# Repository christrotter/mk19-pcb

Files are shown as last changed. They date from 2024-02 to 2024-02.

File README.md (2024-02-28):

# mk19-pcb
The antithesis of 'keep it simple, stupid' - all the features, all the time.

Do you need...
- To use the [Cyboard flex-pcb system](https://www.cyboard.digital/product-page/dactyl-flex-pcbs)?  [and extend it?](https://github.com/christrotter/macropad-pcb)?
- Two [Ultrafalcons](https://github.com/christrotter/ultrafalcon)...per side?
- SPI devices
  - PMW3360/3389 (_right side only_)
  - Dual GC9A01 TFTs per side
  - Quad-shift register-powered 32 pins for rows/cols? ([available as a dedicated breakout here](https://github.com/christrotter/shift-register-spi-breakout-pcb))
- [5-way switch](https://github.com/christrotter/5way-pcb) or [RKJXT](https://github.com/christrotter/rkjxt-mini-breakout) for arrow keys?
- Perhaps enough RGB to illumine your entire home? (_and almost certainly require 5v supplementary power - a feature, not a bug!_)  
- Audio and ADC breakouts?  Reset switch? Power and debug breakouts?
- And use an existing RP Pico to do it?

...probably not, which is why I had to design my own pcb.  So here it is...

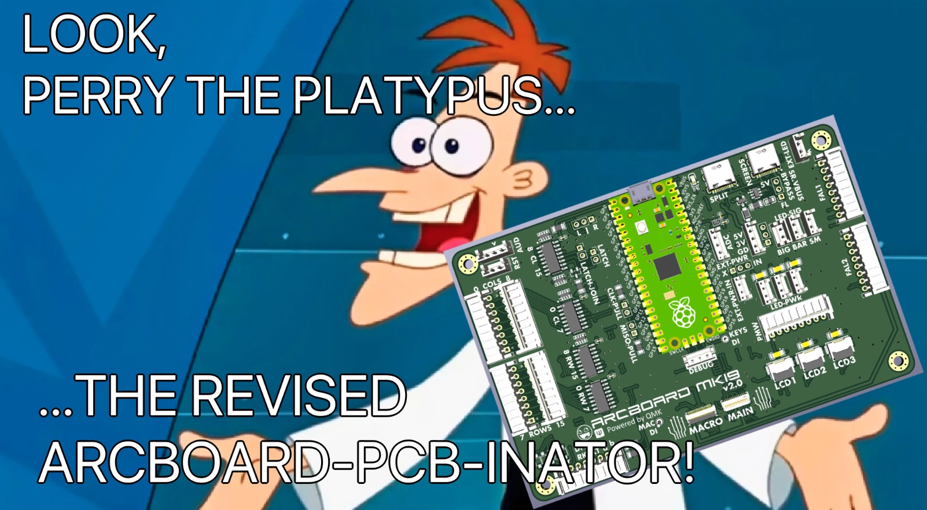
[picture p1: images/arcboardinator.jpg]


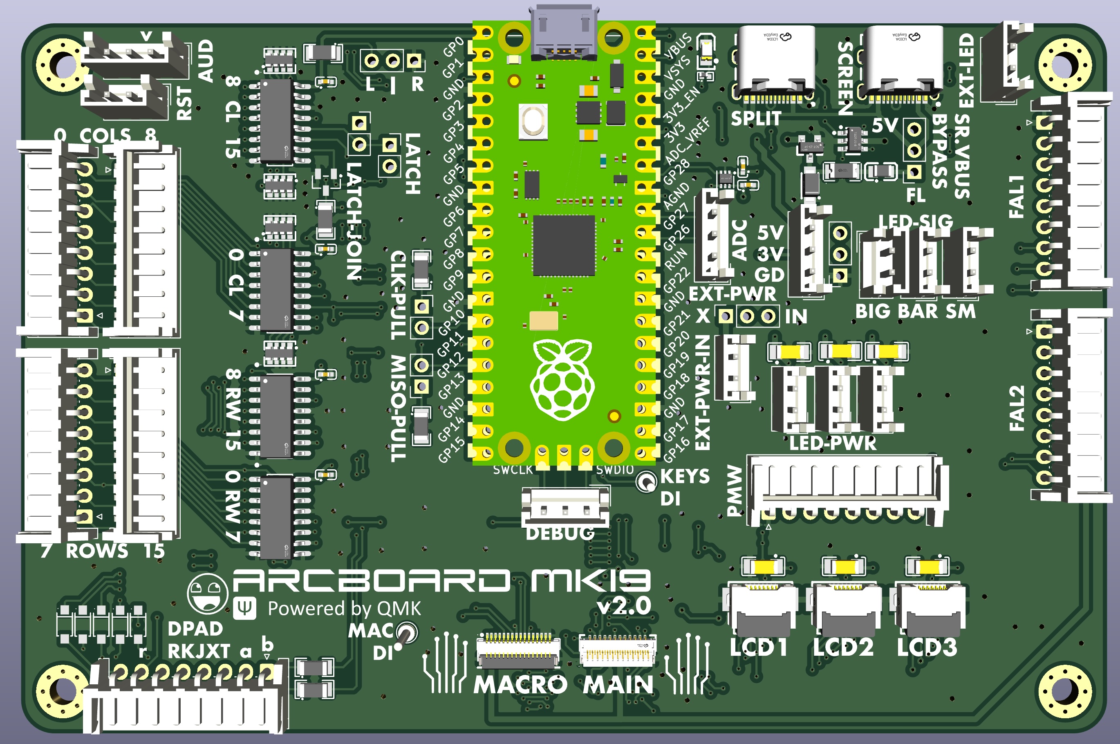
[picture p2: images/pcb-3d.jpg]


# the community that built it
- burkfers (research assistant extraordinaire)
- bomtarnes, chefcooke, walrus, wimads, yingeling, genki, others for design/3d printing help
- Quentin @ BKB & Erik @ Cyboard
- casuanoob (Falcon and diy pcb inspiration)
- tzarc, freznel, KarlK90, Dr. Faustroll, GeorgeN, (and others!) work on shift registers, pcbs, etc
- BKB discord crew; QMK discord; fingerpunch discord (Sadek and Melon, thanks!)
- cardiactuna for the font suggestion

# rev2 improvements
- added rkjxt to dpad connector
- added resistor networks for col shift register pulldown
- relocated cyboard connectors
- fixed a bunch of incorrect pinout orderings
- changed from solder pads to pin jumpers
- re-thought led bypass
- moved TFTs to FFC cables, made 3 of them
- added external 5v power source option
- re-thought the test pins

# design goals
- Provide a re-usable platform for the arcboards
- Make it possible to use the Cyboard flex-pcb system to save on the madness of per-key pcb soldering
- Minimize GPIO usage by moving cols/rows over to shift registers
- Reduce the amount of fiddly soldering and wire stripping a normal hand-wire build requires of you
- USB-C interconnects
- General improvements on the mk17 as a whole

## feature details
- Raspberry PI Pico (RP2040) footprint - just add pin headers and solder away - or, solder directly to pads
- keys provided through the [Cyboard flex-pcb system](https://www.cyboard.digital/product-page/dactyl-flex-pcbs) or, JST-XH 2.54 headers
- macropad using Cyboard flex-pcb keys, custom breakout pcb: https://github.com/christrotter/macropad-pcb (0.5mm pitch 16-pin FFC cable)
  - in future I'd just make this a custom FPC cable
- dpad using custom breakout pcbs [5-way switch](https://github.com/christrotter/5way-pcb) or [RKJXT](https://github.com/christrotter/rkjxt-mini-breakout)
 - diodes are configured for ROW2COL (_to match Cyboard_)
- USB-C split connector w. tzarc-grade voltage protection
 - included a solder pad jumper to bypass if needed
- split-handedness via pin (jumper)
- SPI breakouts
  - PMW33xx
  - 3x TFT LCD (e.g. GC9A01)
  - shift registers (595 for rows, 589 for cols)
- pin breakouts
 - power, debug, ADC, audio, reset
 - remaining GPIO pins
 - test points
- led breakouts w. bypasses
 - keys
 - 2x falcon pcbs
 - indicator strip
 - screen-mounted external indicators via USB-C
  - this passes 5v/GND, level-shifted 5v LED DI/DO signal via USB-C cable
 - pin for whatever else you want to add to the chain

## pcb features
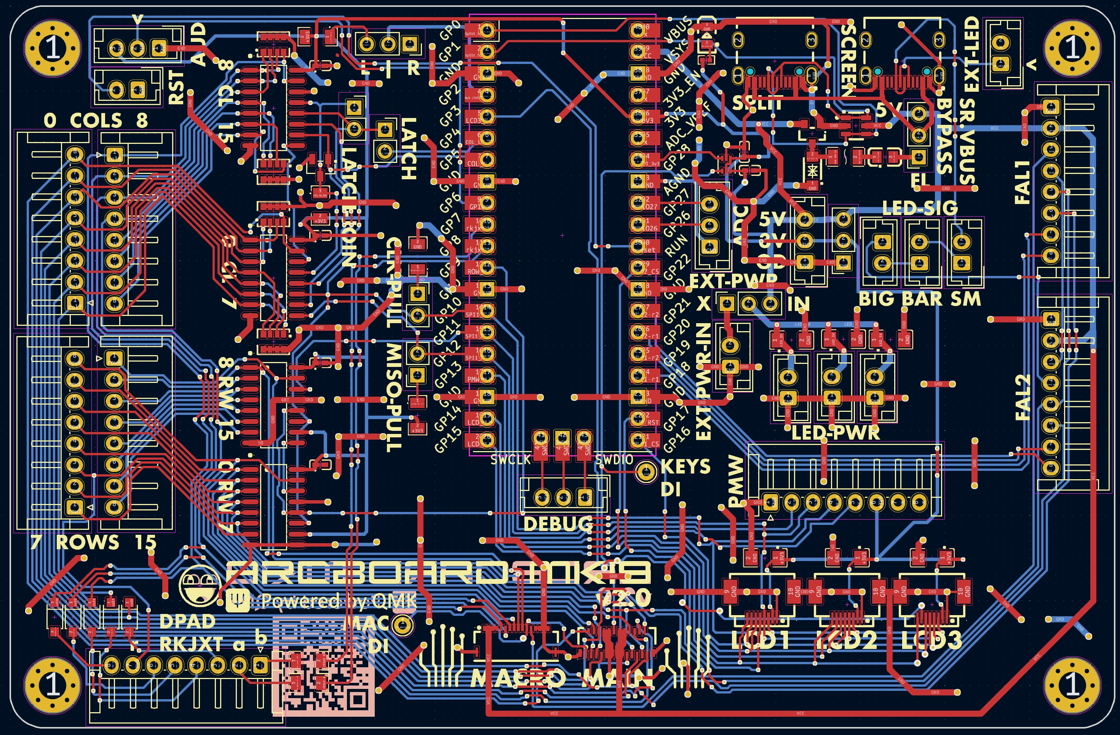
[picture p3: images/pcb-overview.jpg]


- two-layer pcb w. dual ground planes tied w. vias
- components configured as per datasheets
- bypass capacitors!
- care taken to avoid power running alongside signal for too long



# schematic overview
## mcu
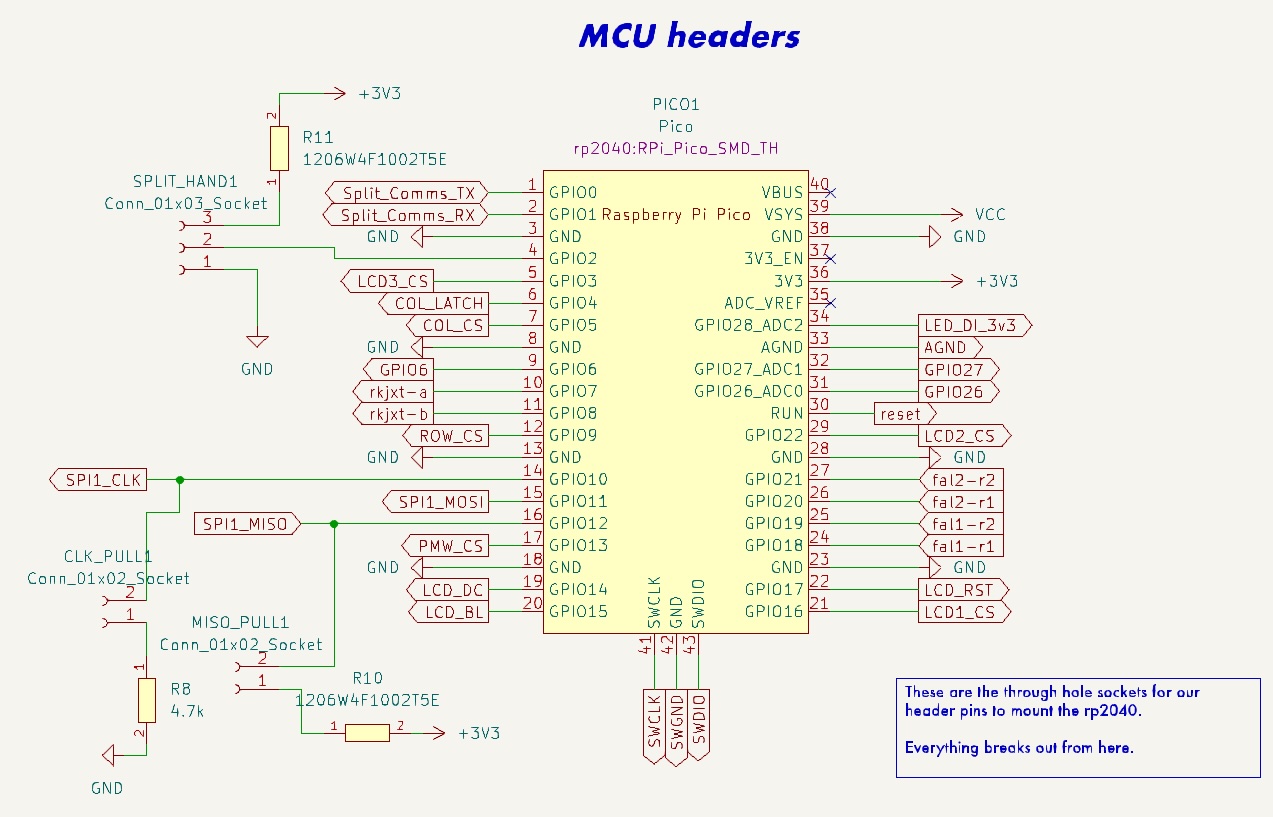
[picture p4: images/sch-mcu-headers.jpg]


## keys via shift registers
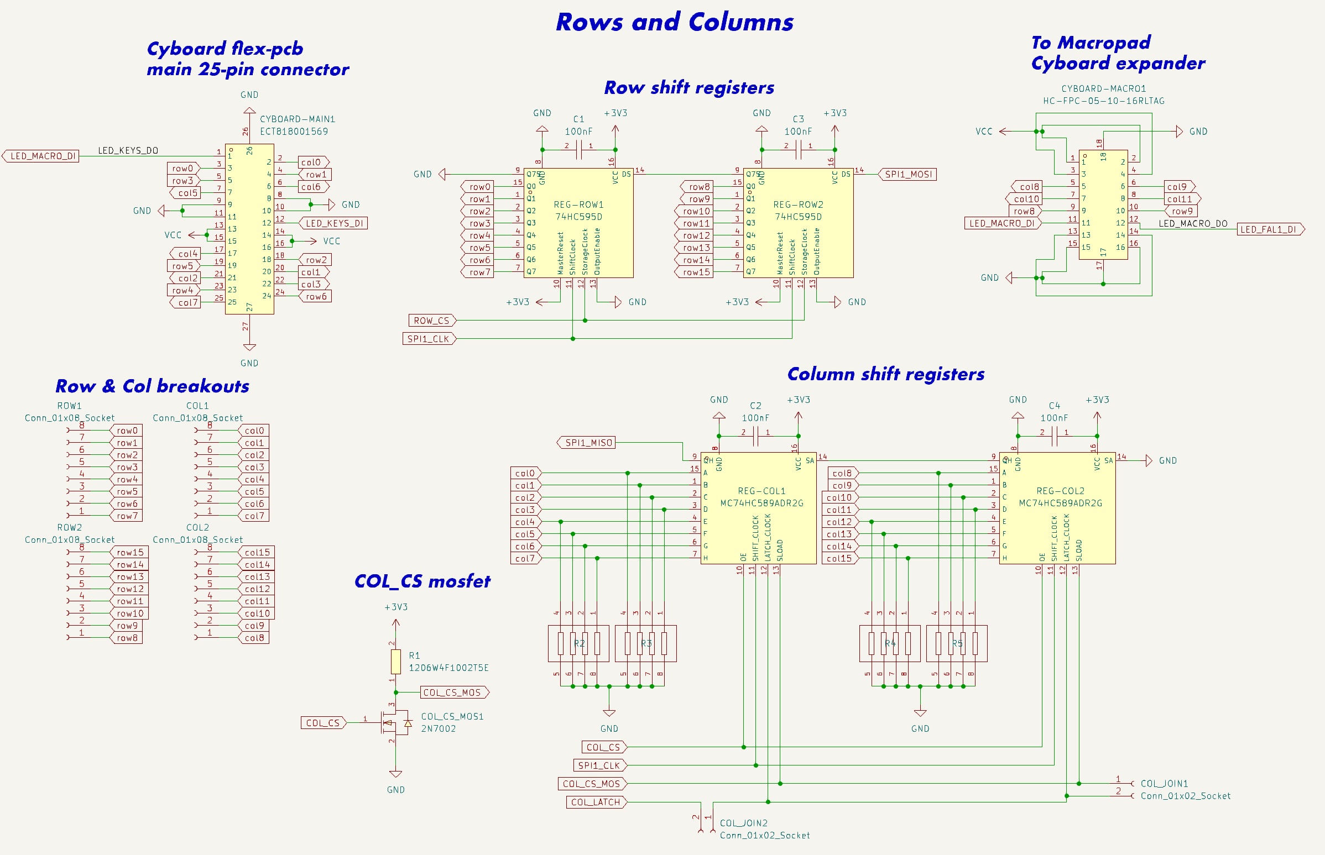
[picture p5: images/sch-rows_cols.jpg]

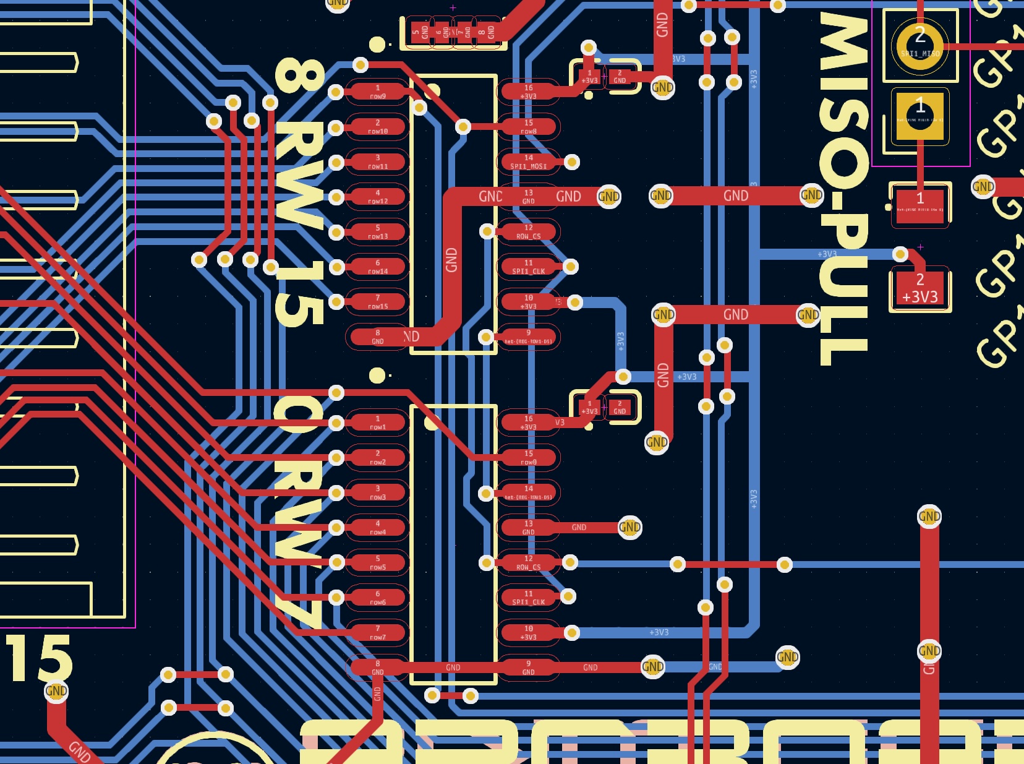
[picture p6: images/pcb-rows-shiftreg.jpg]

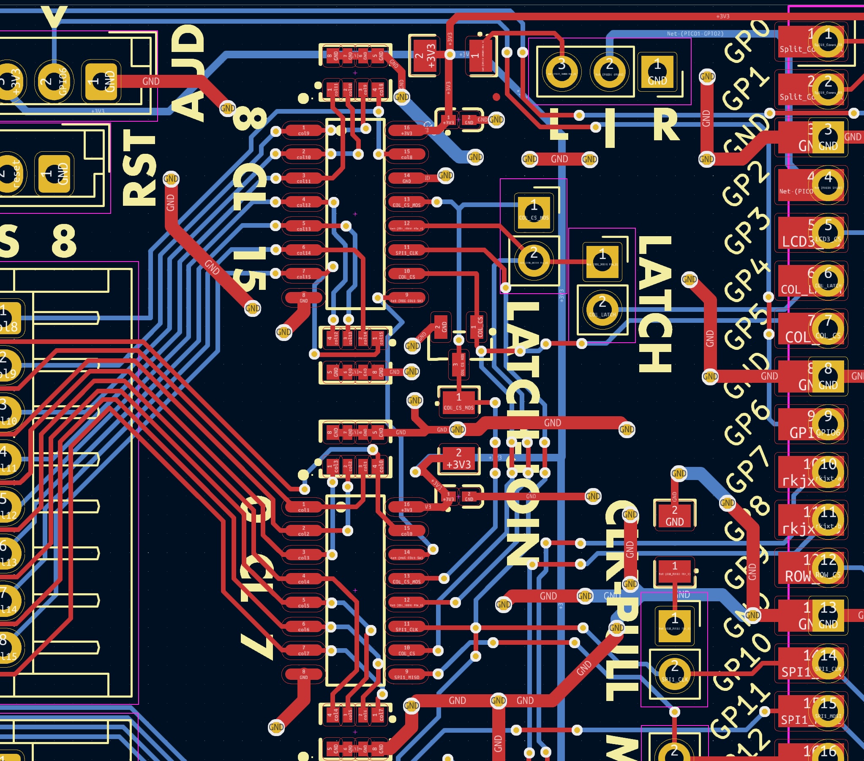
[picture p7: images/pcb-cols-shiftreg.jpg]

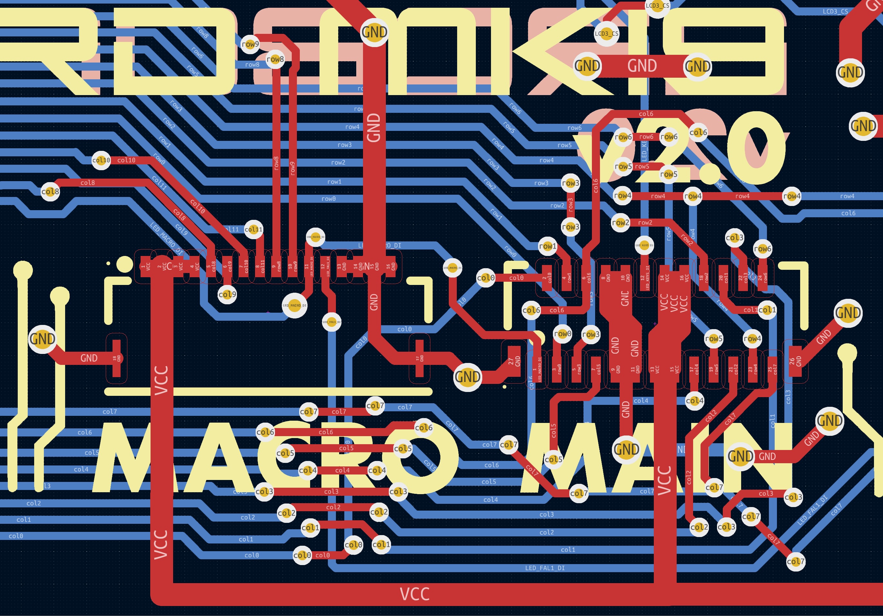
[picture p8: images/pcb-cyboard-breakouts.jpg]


## peripherals
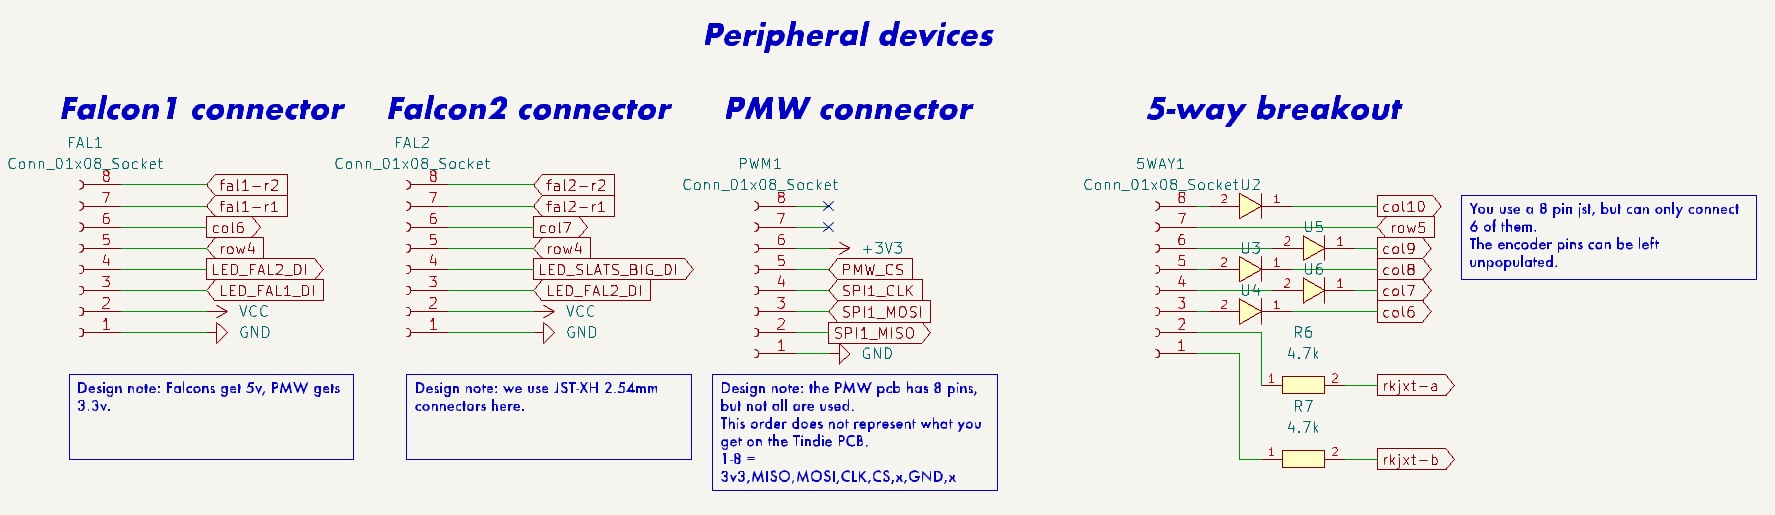
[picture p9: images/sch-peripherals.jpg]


## usb connections
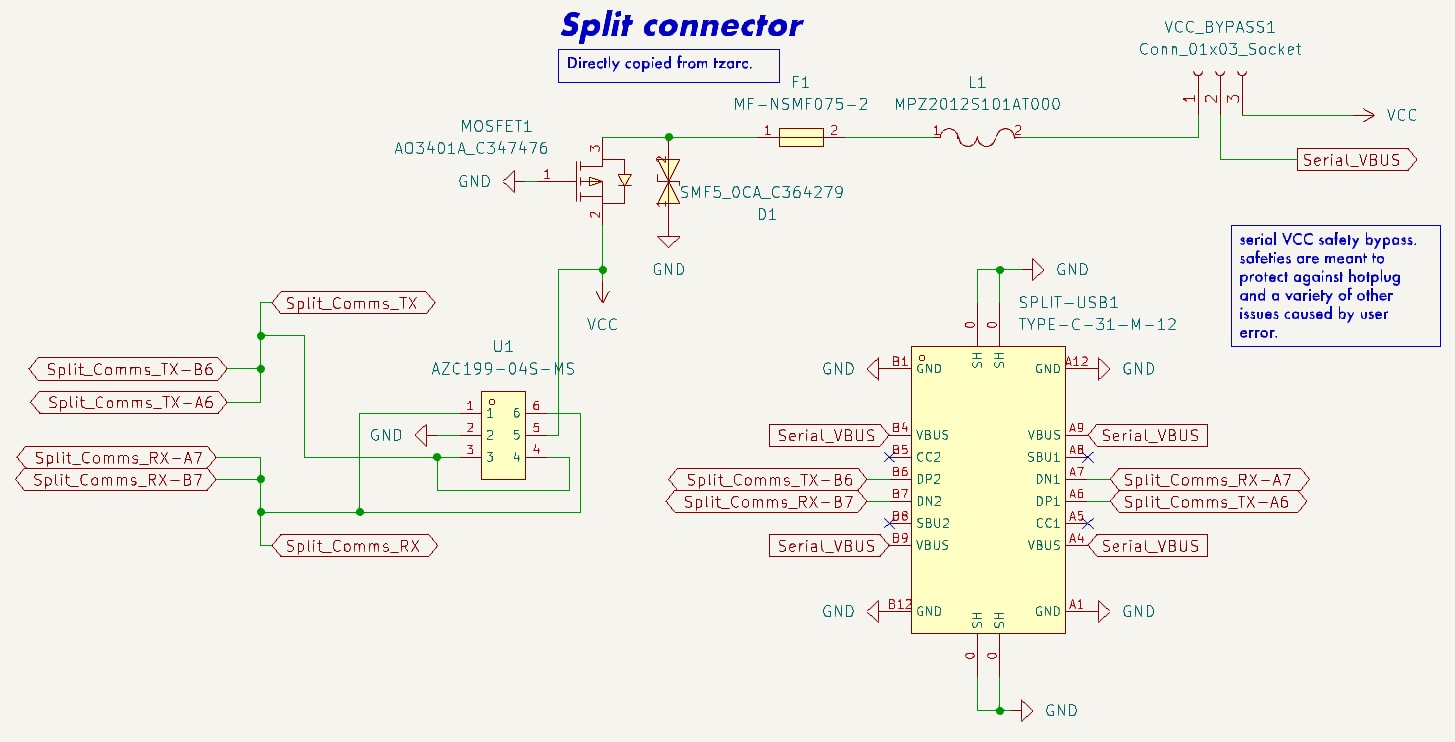
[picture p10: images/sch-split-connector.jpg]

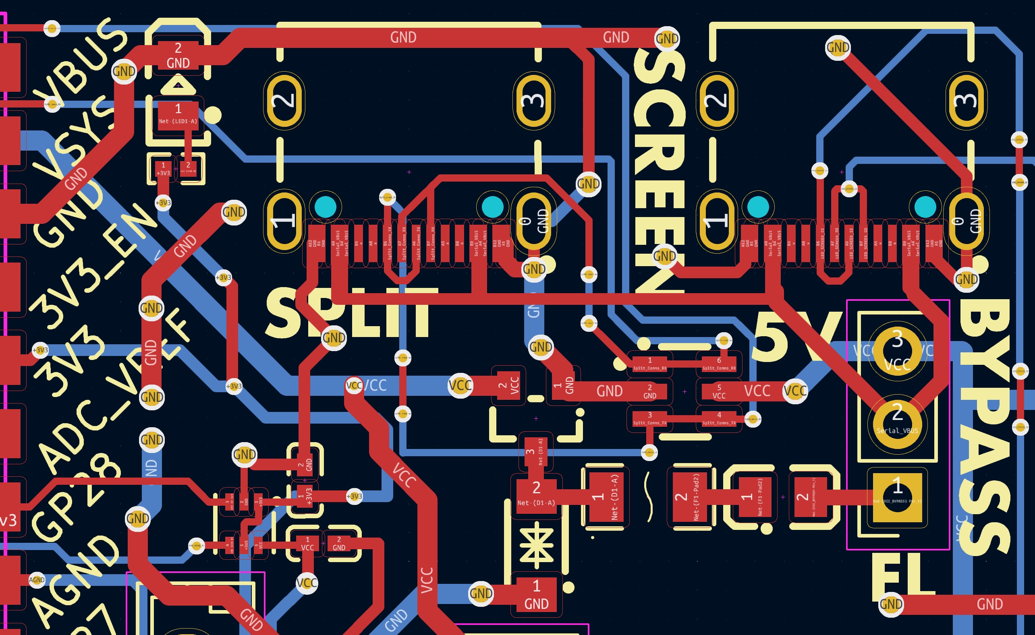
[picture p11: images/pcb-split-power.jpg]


## breakouts
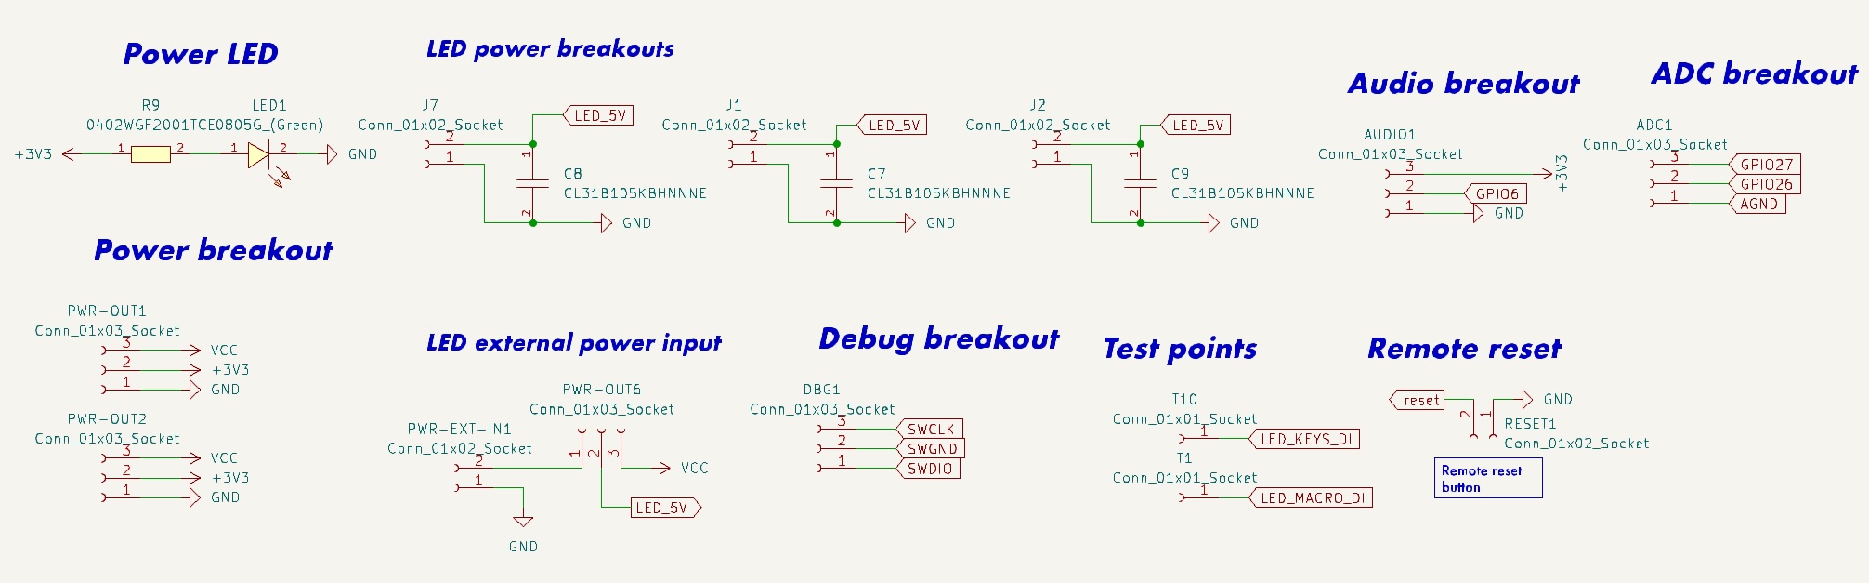
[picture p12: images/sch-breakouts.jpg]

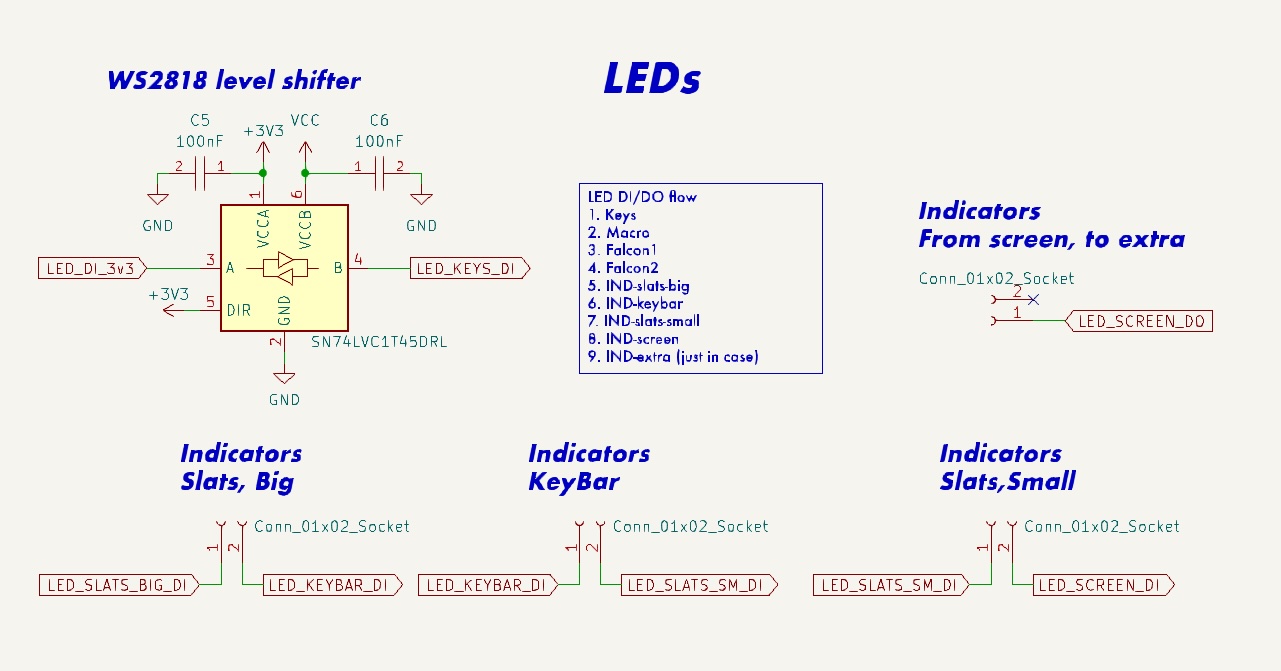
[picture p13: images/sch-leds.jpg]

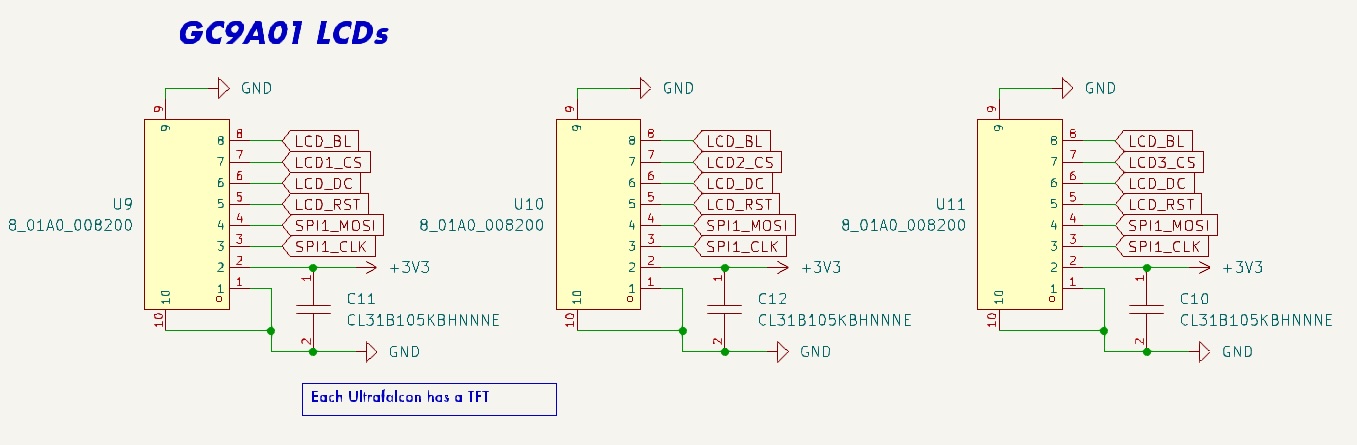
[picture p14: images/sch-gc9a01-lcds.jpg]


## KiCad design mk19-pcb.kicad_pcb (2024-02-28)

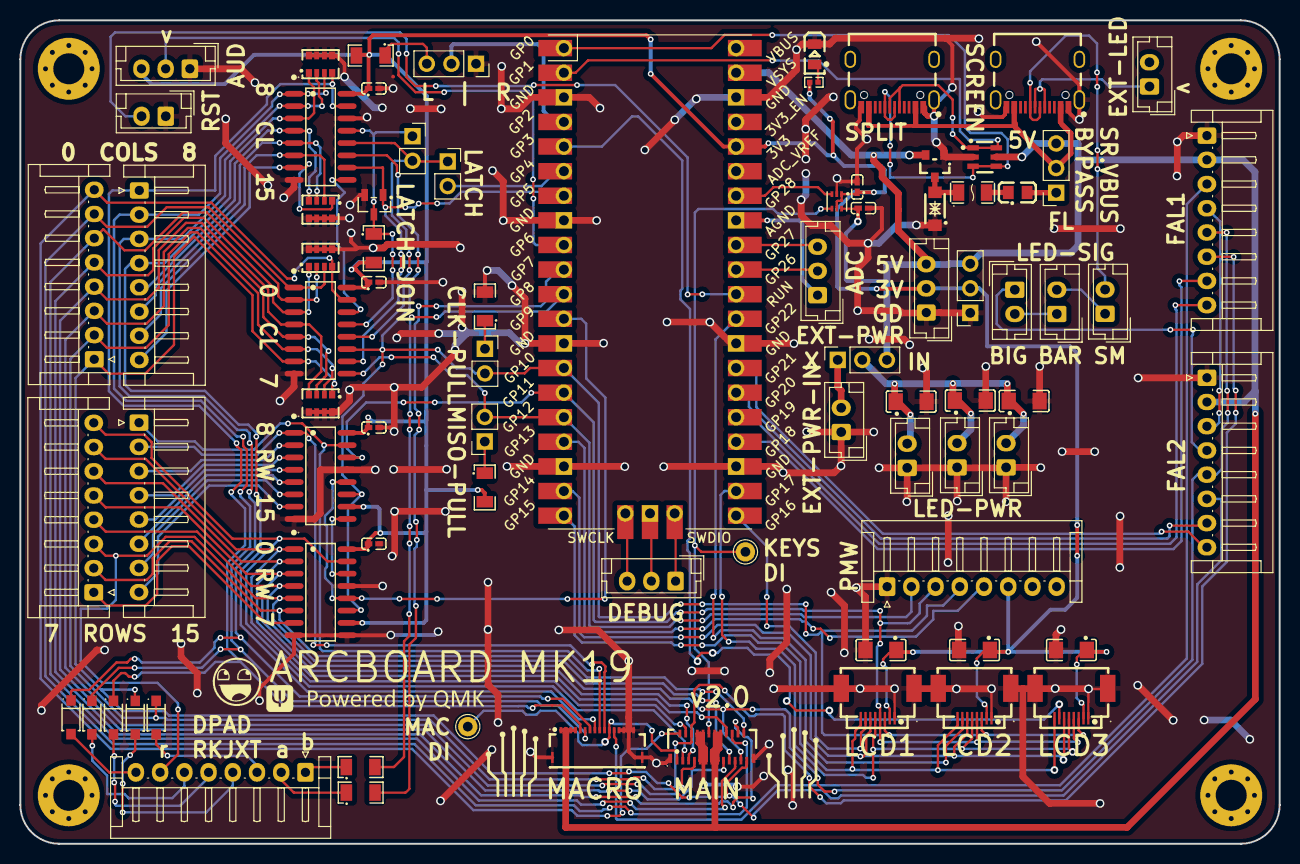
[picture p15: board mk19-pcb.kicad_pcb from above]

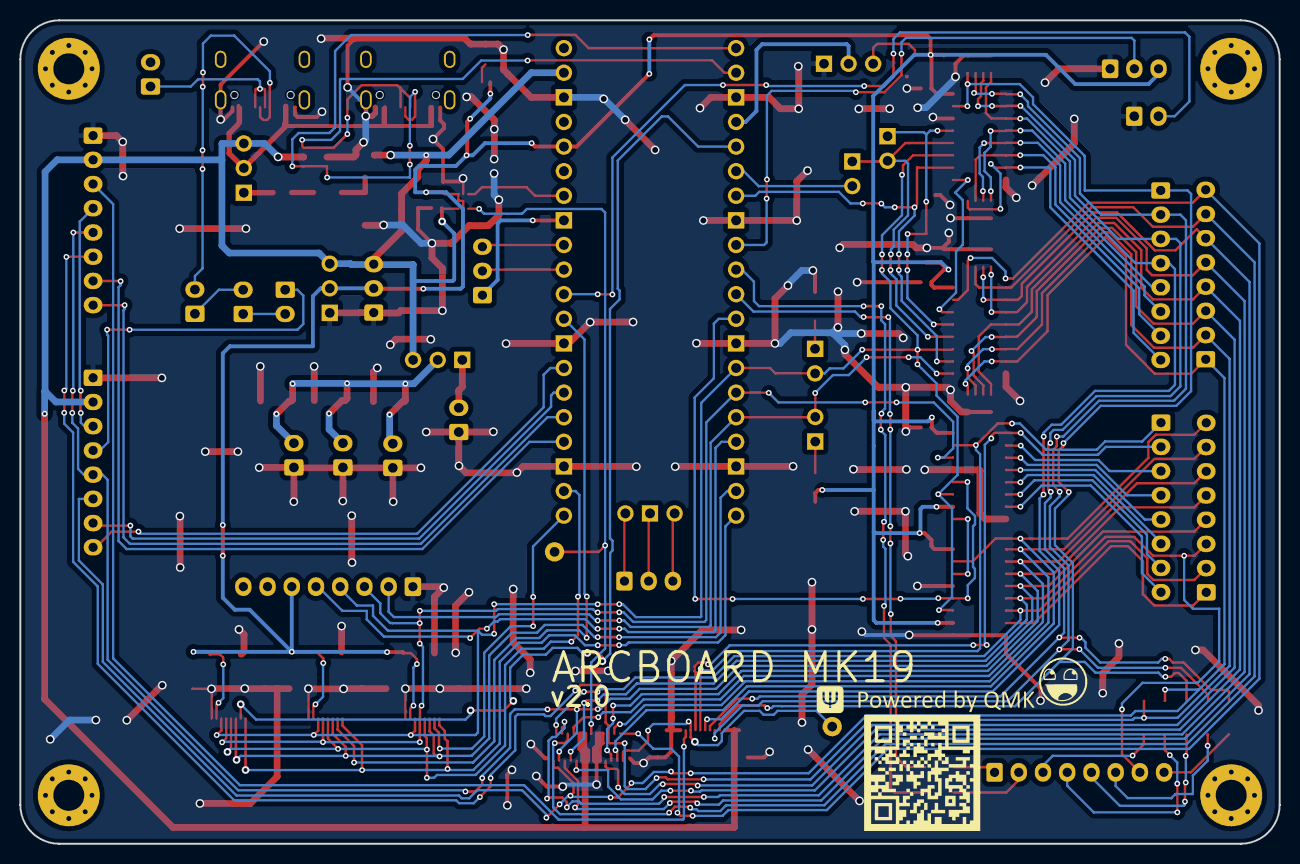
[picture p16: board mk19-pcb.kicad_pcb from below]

Board: 2 copper layers, 130.0 x 85.0 mm, 90 parts (3 on the bottom side), 96 nets.

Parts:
5WAY1: Conn_01x08_Socket; JST_EH_S8B-EH_1x08_P2.50mm_Horizontal
ADC1: Conn_01x03_Socket; JST_EH_B3B-EH-A_1x03_P2.50mm_Vertical
AUDIO1: Conn_01x03_Socket; JST_EH_B3B-EH-A_1x03_P2.50mm_Vertical
C1, C2, C3, C4, C5, C6: 100nF; C0402
C7, C8, C9, C10, C11, C12: CL31B105KBHNNNE; C1206
CLK_PULL1: Conn_01x02_Socket; PinSocket_1x02_P2.54mm_Vertical
COL1, COL2: Conn_01x08_Socket; JST_EH_S8B-EH_1x08_P2.50mm_Horizontal
COL_CS_MOS1: 2N7002; SOT-23-3_L2.9-W1.3-P1.90-LS2.4-BR
COL_JOIN1, COL_JOIN2: Conn_01x02_Socket; PinSocket_1x02_P2.54mm_Vertical
CYBOARD-MACRO1: HC-FPC-05-10-16RLTAG; FPC-SMD_16P-P0.50_HCTL_HC-FPC-05-10-16RLTAG
CYBOARD-MAIN1: ECT818001569; FPC-SMD_ECT818001569
D1: SMF5_0CA_C364279; SOD-123FL_L2.8-W1.8-LS3.7-BI
DBG1: Conn_01x03_Socket; JST_EH_B3B-EH-A_1x03_P2.50mm_Vertical
F1: MF-NSMF075-2; F1206
FAL1, FAL2: Conn_01x08_Socket; JST_EH_S8B-EH_1x08_P2.50mm_Horizontal
H1, H2, H3, H4: MountingHole; MountingHole_3.2mm_M3_Pad_Via
J1, J2, J4, J7, J9, J10, J11: Conn_01x02_Socket; JST_EH_B2B-EH-A_1x02_P2.50mm_Vertical
L1: MPZ2012S101AT000; L0805
LED1: 0805G_(Green); LED0805-R-RD
LED-LVL1: SN74LVC1T45DRL; SOT-563_L1.6-W1.2-P0.50-LS1.6-BR
LOGO1, LOGO3: **REF; awesome-logo
LOGO2, LOGO4: **REF; qmk-lite
LOGO5: **REF; mk19-qr-logo-12mm
LOGO6, LOGO7: **REF; cyboard-logo-10mm
MISO_PULL1: Conn_01x02_Socket; PinSocket_1x02_P2.54mm_Vertical
MOSFET1: AO3401A_C347476; SOT-23_L2.9-W1.3-P1.90-LS2.4-BR
PICO1: Pico; RPi_Pico_SMD_TH
PWM1: Conn_01x08_Socket; JST_EH_S8B-EH_1x08_P2.50mm_Horizontal
PWR-EXT-IN1: Conn_01x02_Socket; JST_EH_B2B-EH-A_1x02_P2.50mm_Vertical
PWR-OUT1: Conn_01x03_Socket; JST_EH_B3B-EH-A_1x03_P2.50mm_Vertical
PWR-OUT2, PWR-OUT6: Conn_01x03_Socket; PinSocket_1x03_P2.54mm_Vertical
R1, R10, R11: 1206W4F1002T5E; R1206
R2, R3, R4, R5: 4D03WGJ0103T5E; RES-ARRAY-SMD_0603-8P-L3.2-W1.6-BL
R6, R7, R8: 4.7k; R1206
R9: 0402WGF2001TCE; R0402
REG-COL1, REG-COL2: MC74HC589ADR2G; SOIC-16_L9.9-W3.9-P1.27-LS6.0-BL
REG-ROW1, REG-ROW2: 74HC595D; SOIC-16_L9.9-W3.9-P1.27-LS6.0-BL
RESET1: Conn_01x02_Socket; JST_EH_B2B-EH-A_1x02_P2.50mm_Vertical
ROW1, ROW2: Conn_01x08_Socket; JST_EH_S8B-EH_1x08_P2.50mm_Horizontal
SCREEN1: TYPE-C-31-M-12; USB-C_SMD-TYPE-C-31-M-12
SPLIT-USB1: TYPE-C-31-M-12; USB-C_SMD-TYPE-C-31-M-12
SPLIT_HAND1: Conn_01x03_Socket; PinSocket_1x03_P2.54mm_Vertical
T1, T10: Conn_01x01_Socket; Pin_D1.0mm_L10.0mm
U1: AZC199-04S-MS; TSOT-23-6_L2.9-W1.6-P0.95-LS2.8-BL
U2, U3, U4, U5, U6: 1N4148W_C81598; SOD-123F_L2.7-W1.6-LS3.8-RD
U9, U10, U11: 8_01A0_008200; FPC-SMD_8P-P0.50_8.01A0.008200
VCC_BYPASS1: Conn_01x03_Socket; PinSocket_1x03_P2.54mm_Vertical

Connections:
+3V3: AUDIO1.3, C1.1, C2.1, C3.1, C4.1, C5.1, C10.1, C11.1, C12.1, LED-LVL1.1 (VCCA), LED-LVL1.5 (DIR), PICO1.36 (3V3), PWM1.6, PWR-OUT1.2, PWR-OUT2.2, R1.2, R9.1, R10.2, R11.2, REG-COL1.16 (VCC), REG-COL2.16 (VCC), REG-ROW1.10 (MasterReset), REG-ROW1.16 (VCC), REG-ROW2.10 (MasterReset), REG-ROW2.16 (VCC), U9.2, U10.2, U11.2
AGND: ADC1.1, PICO1.33 (AGND)
COL_CS: COL_CS_MOS1.1 (G), PICO1.7 (GPIO5), REG-COL1.10 (OE), REG-COL2.10 (OE)
COL_CS_MOS: COL_CS_MOS1.3 (D), COL_JOIN1.1, R1.1, REG-COL1.13 (SLOAD), REG-COL2.13 (SLOAD)
COL_LATCH: COL_JOIN2.2, PICO1.6 (GPIO4)
GND: AUDIO1.1, C1.2, C2.2, C3.2, C4.2, C5.2, C6.2, C7.2, C8.2, C9.2, C10.2, C11.2, C12.2, COL_CS_MOS1.2 (S), CYBOARD-MACRO1.13, CYBOARD-MACRO1.14, CYBOARD-MACRO1.15, CYBOARD-MACRO1.16, CYBOARD-MACRO1.17, CYBOARD-MACRO1.18, CYBOARD-MAIN1.8, CYBOARD-MAIN1.9, CYBOARD-MAIN1.10, CYBOARD-MAIN1.11, CYBOARD-MAIN1.26, CYBOARD-MAIN1.27, D1.1 (K), FAL1.1, FAL2.1, J1.1, J2.1, J7.1, LED1.2 (K), LED-LVL1.2 (GND), MOSFET1.1 (G), PICO1.3 (GND), PICO1.8 (GND), PICO1.13 (GND), PICO1.18 (GND), PICO1.23 (GND), PICO1.28 (GND), PICO1.38 (GND), PWM1.1, PWR-EXT-IN1.1, PWR-OUT1.1, PWR-OUT2.1, R2.5, R2.6, R2.7, R2.8, R3.5, R3.6, R3.7, R3.8, R4.5, R4.6, R4.7, R4.8, R5.5, R5.6, R5.7, R5.8, R8.2, REG-COL1.8 (GND), REG-COL2.8 (GND), REG-COL2.14 (SA), REG-ROW1.8 (GND), REG-ROW1.9 (Q7S), REG-ROW1.13 (OutputEnable), REG-ROW2.8 (GND), REG-ROW2.13 (OutputEnable), RESET1.1, SCREEN1.0 (SH), SCREEN1.A1 (GND), SCREEN1.A12 (GND), SCREEN1.B1 (GND), SCREEN1.B12 (GND), SPLIT-USB1.0 (SH), SPLIT-USB1.A1 (GND), SPLIT-USB1.A12 (GND), SPLIT-USB1.B1 (GND), SPLIT-USB1.B12 (GND), SPLIT_HAND1.1, U1.2, U9.1, U9.9, U9.10, U10.1, U10.9, U10.10, U11.1, U11.9, U11.10
GPIO6: AUDIO1.2, PICO1.9 (GPIO6)
GPIO26: ADC1.2, PICO1.31 (GPIO26_ADC0)
GPIO27: ADC1.3, PICO1.32 (GPIO27_ADC1)
LCD1_CS: PICO1.21 (GPIO16), U9.7
LCD2_CS: PICO1.29 (GPIO22), U10.7
LCD3_CS: PICO1.5 (GPIO3), U11.7
LCD_BL: PICO1.20 (GPIO15), U9.8, U10.8, U11.8
LCD_DC: PICO1.19 (GPIO14), U9.6, U10.6, U11.6
LCD_RST: PICO1.22 (GPIO17), U9.5, U10.5, U11.5
LED_5V: C7.1, C8.1, C9.1, J1.2, J2.2, J7.2, PWR-OUT6.2
LED_DI_3v3: LED-LVL1.3 (A), PICO1.34 (GPIO28_ADC2)
LED_FAL1_DI: CYBOARD-MACRO1.12, FAL1.3
LED_FAL2_DI: FAL1.4, FAL2.3
LED_KEYBAR_DI: J4.1, J10.2
LED_KEYS_DI: CYBOARD-MAIN1.12, LED-LVL1.4 (B), T10.1
LED_MACRO_DI: CYBOARD-MACRO1.11, CYBOARD-MAIN1.1, T1.1
LED_SCREEN_DI: J9.2, SCREEN1.A6 (DP1), SCREEN1.B6 (DP2)
LED_SCREEN_DO: J11.1, SCREEN1.A7 (DN1), SCREEN1.B7 (DN2)
LED_SLATS_BIG_DI: FAL2.4, J10.1
LED_SLATS_SM_DI: J4.2, J9.1
unnamed: 5WAY1.1, R7.1
unnamed: 5WAY1.2, R6.1
unnamed: 5WAY1.3, U4.2 (A)
unnamed: 5WAY1.4, U6.2 (A)
unnamed: 5WAY1.5, U3.2 (A)
unnamed: 5WAY1.6, U5.2 (A)
unnamed: 5WAY1.8, U2.2 (A)
unnamed: CLK_PULL1.1, R8.1
unnamed: COL_JOIN1.2, COL_JOIN2.1, REG-COL1.12 (LATCH_CLOCK), REG-COL2.12 (LATCH_CLOCK)
unnamed: D1.2 (A), F1.1, MOSFET1.3 (D)
unnamed: F1.2, L1.1
unnamed: LED1.1 (A), R9.2
unnamed: MISO_PULL1.1, R10.1
unnamed: PICO1.4 (GPIO2), SPLIT_HAND1.2
unnamed: PWR-EXT-IN1.2, PWR-OUT6.1
unnamed: REG-COL1.14 (SA), REG-COL2.9 (QH)
unnamed: REG-ROW1.14 (DS), REG-ROW2.9 (Q7S)
unnamed: R11.1, SPLIT_HAND1.3
unnamed: L1.2, VCC_BYPASS1.1
PMW_CS: PICO1.17 (GPIO13), PWM1.5
ROW_CS: PICO1.12 (GPIO9), REG-ROW1.12 (StorageClock), REG-ROW2.12 (StorageClock)
SPI1_CLK: CLK_PULL1.2, PICO1.14 (GPIO10), PWM1.4, REG-COL1.11 (SHIFT_CLOCK), REG-COL2.11 (SHIFT_CLOCK), REG-ROW1.11 (ShiftClock), REG-ROW2.11 (ShiftClock), U9.3, U10.3, U11.3
SPI1_MISO: MISO_PULL1.2, PICO1.16 (GPIO12), PWM1.2, REG-COL1.9 (QH)
SPI1_MOSI: PICO1.15 (GPIO11), PWM1.3, REG-ROW2.14 (DS), U9.4, U10.4, U11.4
SWCLK: DBG1.3, PICO1.41 (SWCLK)
SWDIO: DBG1.1, PICO1.43 (SWDIO)
SWGND: DBG1.2, PICO1.42 (GND)
Serial_VBUS: SCREEN1.A4 (VBUS), SCREEN1.A9 (VBUS), SCREEN1.B4 (VBUS), SCREEN1.B9 (VBUS), SPLIT-USB1.A4 (VBUS), SPLIT-USB1.A9 (VBUS), SPLIT-USB1.B4 (VBUS), SPLIT-USB1.B9 (VBUS), VCC_BYPASS1.2
Split_Comms_RX: PICO1.2 (GPIO1), SPLIT-USB1.A7 (DN1), SPLIT-USB1.B7 (DN2), U1.1, U1.6
Split_Comms_TX: PICO1.1 (GPIO0), SPLIT-USB1.A6 (DP1), SPLIT-USB1.B6 (DP2), U1.3, U1.4
VCC: C6.1, CYBOARD-MACRO1.1, CYBOARD-MACRO1.2, CYBOARD-MACRO1.3, CYBOARD-MACRO1.4, CYBOARD-MAIN1.13, CYBOARD-MAIN1.14, CYBOARD-MAIN1.15, CYBOARD-MAIN1.16, FAL1.2, FAL2.2, LED-LVL1.6 (VCCB), MOSFET1.2 (S), PICO1.39 (VSYS), PWR-OUT1.3, PWR-OUT2.3, PWR-OUT6.3, U1.5, VCC_BYPASS1.3
col0: COL1.8, CYBOARD-MAIN1.2, R3.4, REG-COL1.15 (A)
col1: COL1.7, CYBOARD-MAIN1.20, R3.3, REG-COL1.1 (B)
col2: COL1.6, CYBOARD-MAIN1.21, R3.2, REG-COL1.2 (C)
col3: COL1.5, CYBOARD-MAIN1.22, R3.1, REG-COL1.3 (D)
col4: COL1.4, CYBOARD-MAIN1.17, R2.4, REG-COL1.4 (E)
col5: COL1.3, CYBOARD-MAIN1.7, R2.3, REG-COL1.5 (F)
col6: COL1.2, CYBOARD-MAIN1.6, FAL1.6, R2.2, REG-COL1.6 (G), U4.1 (K)
col7: COL1.1, CYBOARD-MAIN1.25, FAL2.6, R2.1, REG-COL1.7 (H), U6.1 (K)
col8: COL2.1, CYBOARD-MACRO1.5, R5.4, REG-COL2.15 (A), U3.1 (K)
col9: COL2.2, CYBOARD-MACRO1.6, R5.3, REG-COL2.1 (B), U5.1 (K)
col10: COL2.3, CYBOARD-MACRO1.7, R5.2, REG-COL2.2 (C), U2.1 (K)
col11: COL2.4, CYBOARD-MACRO1.8, R5.1, REG-COL2.3 (D)
col12: COL2.5, R4.4, REG-COL2.4 (E)
col13: COL2.6, R4.3, REG-COL2.5 (F)
col14: COL2.7, R4.2, REG-COL2.6 (G)
col15: COL2.8, R4.1, REG-COL2.7 (H)
fal1-r1: FAL1.7, PICO1.24 (GPIO18)
fal1-r2: FAL1.8, PICO1.25 (GPIO19)
fal2-r1: FAL2.7, PICO1.26 (GPIO20)
fal2-r2: FAL2.8, PICO1.27 (GPIO21)
reset: PICO1.30 (RUN), RESET1.2
rkjxt-a: PICO1.10 (GPIO7), R6.2
rkjxt-b: PICO1.11 (GPIO8), R7.2
row0: CYBOARD-MAIN1.3, REG-ROW1.15 (Q0), ROW1.8
row1: CYBOARD-MAIN1.4, REG-ROW1.1 (Q1), ROW1.7
row2: CYBOARD-MAIN1.18, REG-ROW1.2 (Q2), ROW1.6
row3: CYBOARD-MAIN1.5, REG-ROW1.3 (Q3), ROW1.5
row4: CYBOARD-MAIN1.23, FAL1.5, FAL2.5, REG-ROW1.4 (Q4), ROW1.4
row5: 5WAY1.7, CYBOARD-MAIN1.19, REG-ROW1.5 (Q5), ROW1.3
row6: CYBOARD-MAIN1.24, REG-ROW1.6 (Q6), ROW1.2
row7: REG-ROW1.7 (Q7), ROW1.1
row8: CYBOARD-MACRO1.9, REG-ROW2.15 (Q0), ROW2.1
row9: CYBOARD-MACRO1.10, REG-ROW2.1 (Q1), ROW2.2
row10: REG-ROW2.2 (Q2), ROW2.3
row11: REG-ROW2.3 (Q3), ROW2.4
row12: REG-ROW2.4 (Q4), ROW2.5
row13: REG-ROW2.5 (Q5), ROW2.6
row14: REG-ROW2.6 (Q6), ROW2.7
row15: REG-ROW2.7 (Q7), ROW2.8

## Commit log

2024-02-14 getting the schematic updated, adding missing features
    [mk19-pcb.kicad_pcb, mk19-pcb.kicad_sch]
2024-02-16 all new features added, fixes implemented, ready to start arranging and routing
    [mk19-pcb.kicad_pcb, mk19-pcb.kicad_sch]
2024-02-17 feb16 work, almost ready to start running traces
    [mk19-pcb.kicad_pcb, mk19-pcb.kicad_sch]
2024-02-17 first draft done - needs work on led signal flow, silkscreen, falcon row-col thing.
    [mk19-pcb.kicad_pcb, mk19-pcb.kicad_sch]
2024-02-18 ready for review
    [mk19-pcb.kicad_pcb, mk19-pcb.kicad_sch]
2024-02-18 missed cyboard branding, added a test pin for macro led DI
    [mk19-pcb.kicad_pcb, mk19-pcb.kicad_sch]
2024-02-18 more minor fixes
    [mk19-pcb.kicad_pcb, mk19-pcb.kicad_sch]
2024-02-18 adding jumper for clk pulldown
    [mk19-pcb.kicad_pcb, mk19-pcb.kicad_sch]
2024-02-19 production files
    [mk19-pcb.kicad_pcb, mk19-pcb.kicad_sch]
2024-02-21 just minor 3d file changes
    [mk19-pcb.kicad_pcb]
2024-02-22 working on improving the readme
    [mk19-pcb.kicad_sch]
